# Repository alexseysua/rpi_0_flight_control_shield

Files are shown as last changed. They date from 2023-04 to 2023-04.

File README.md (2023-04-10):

# Flight Control Shield for Raspberry Pi Zero

## Description
A small hobby electronics project - hardware interface 
for intelligent autonomous UAVs. The board is designed 
to be plugged into the Raspberry Pi Zero pin socket, to 
form a consistent flight control system. It is the 
same concept as Navio2 or the Navigator, but for a smaller board. 

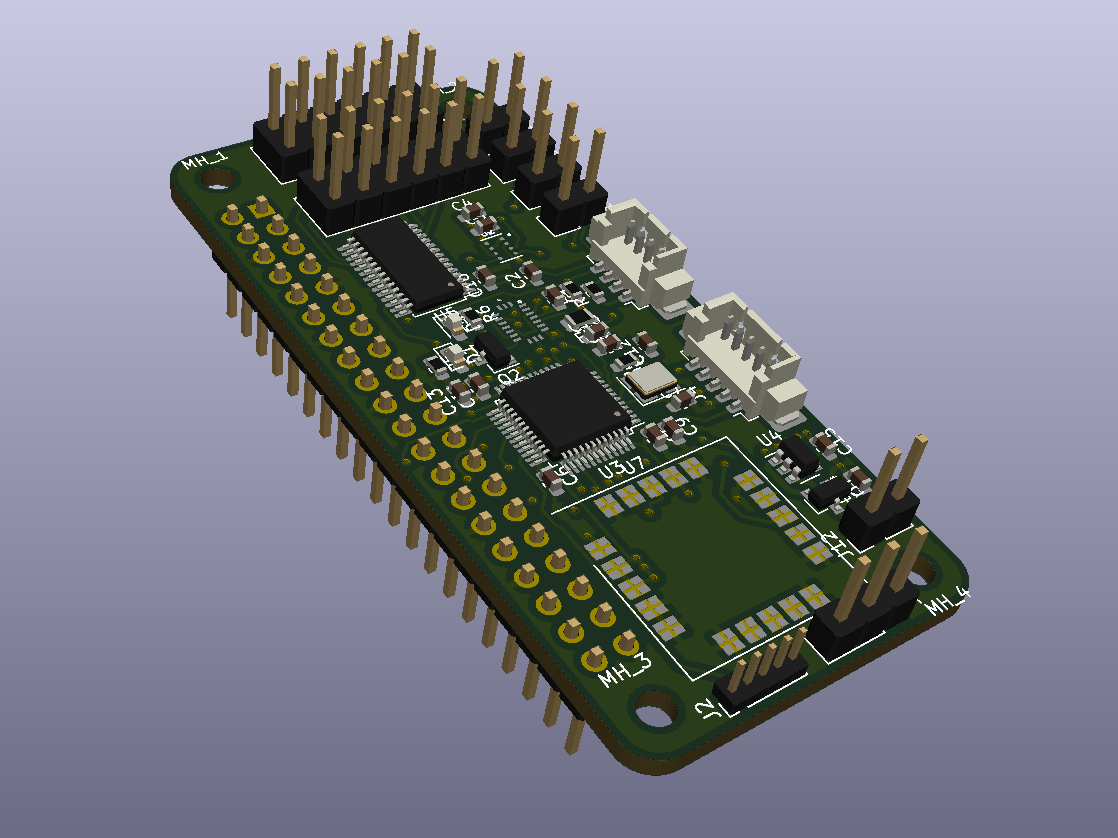
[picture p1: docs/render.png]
render


## Onboard systems
* Main CPU - STM32F103CBT 
* IMU - BMX055
* Barometer - DPS310XTSA1
* ADC sensor ports
* 12 PWM ports - PCA9685PW
* Serial and I2C extension ports
* GNSS receiver - SAM M8Q

At the moment of designing (August 2022) these were all available on JLCPCB. 

## Firmware?

Not at this time :c Slightly tweaked ArduPilot (popular stuff, it is running on ChibiOS) will probably be a good fit.

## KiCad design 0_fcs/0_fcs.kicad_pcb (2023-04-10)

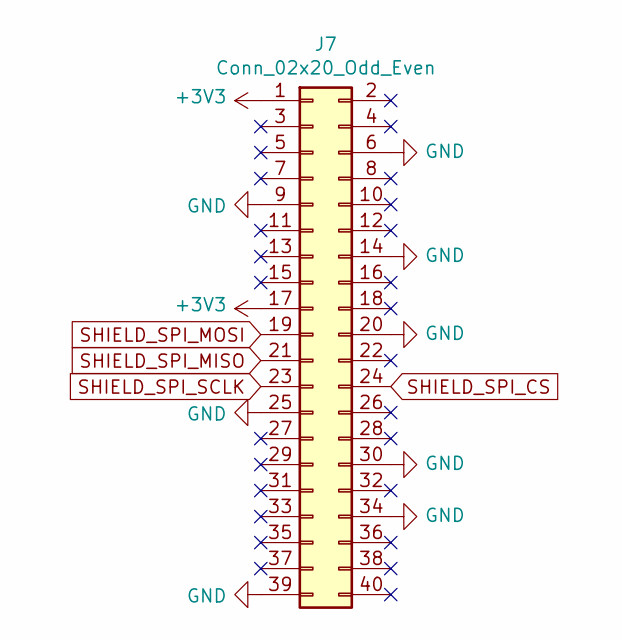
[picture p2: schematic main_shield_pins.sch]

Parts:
J7: Conn_02x20_Odd_Even; PinHeader_2x20_P2.54mm_Vertical

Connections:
GND: J7.6, J7.9, J7.14, J7.20, J7.25, J7.30, J7.34, J7.39; also elsewhere on the board
SHIELD_SPI_CS: J7.24; also elsewhere on the board
SHIELD_SPI_MISO: J7.21; also elsewhere on the board
SHIELD_SPI_MOSI: J7.19; also elsewhere on the board
SHIELD_SPI_SCLK: J7.23; also elsewhere on the board

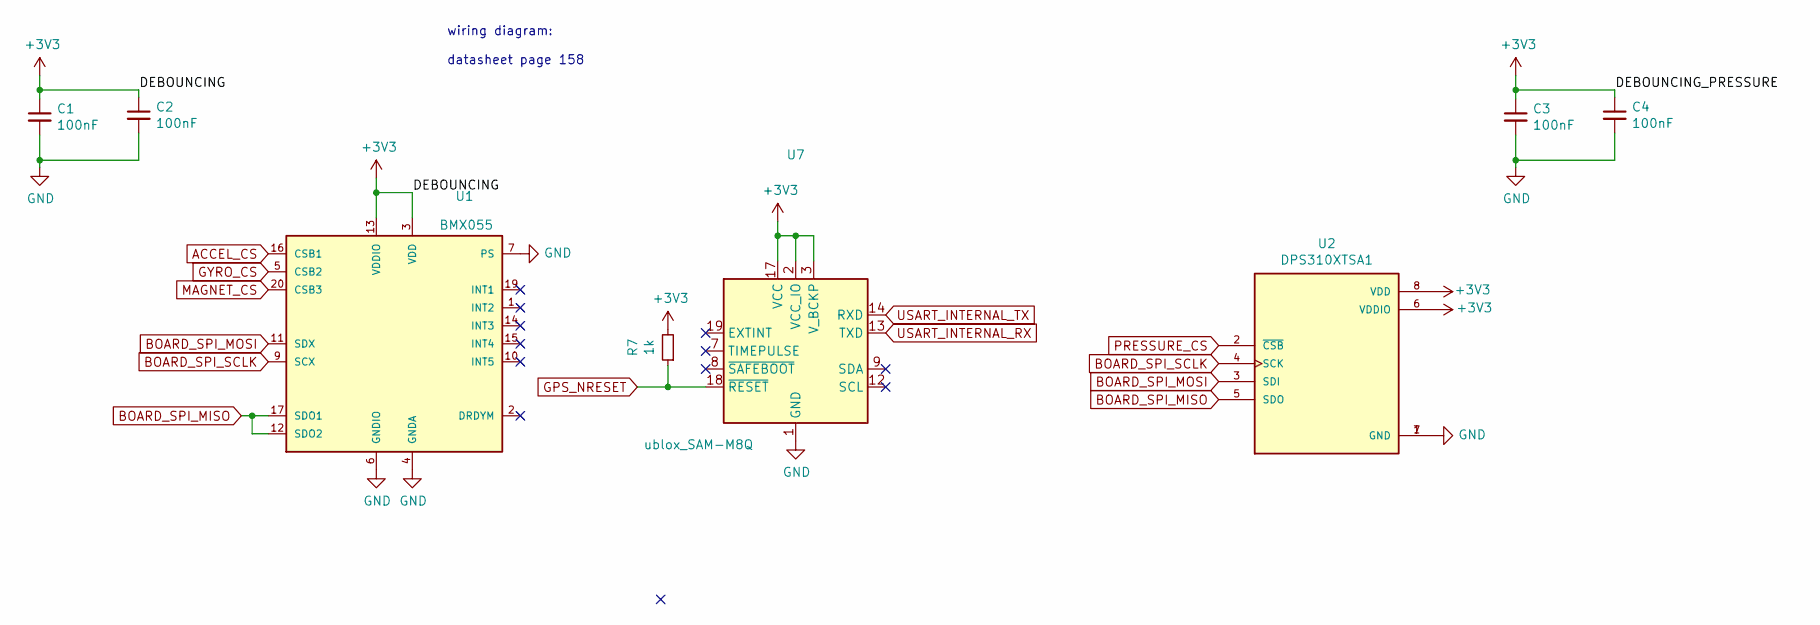
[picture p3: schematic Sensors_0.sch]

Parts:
C1, C2, C3, C4: 100nF; C_0603_1608Metric
R7: 1k; R_0603_1608Metric
U1: BMX055
U2: DPS310XTSA1; XDCR_DPS310XTSA1
U7: ublox_SAM-M8Q

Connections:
ACCEL_CS: U1.16 (CSB1); also elsewhere on the board
BOARD_SPI_MISO: U1.12 (SDO2), U1.17 (SDO1), U2.5 (SDO); also elsewhere on the board
BOARD_SPI_MOSI: U1.11 (SDX), U2.3 (SDI); also elsewhere on the board
BOARD_SPI_SCLK: U1.9 (SCX), U2.4 (SCK); also elsewhere on the board
GND: C1.2, C2.2, C3.2, C4.2, U1.4 (GNDA), U1.6 (GNDIO), U1.7 (PS), U2.1 (GND), U2.7 (GND), U7.1 (GND), U7.4 (GND), U7.5 (GND), U7.6 (GND), U7.10 (GND), U7.11 (GND), U7.15 (GND), U7.16 (GND), U7.20 (GND); also elsewhere on the board
GPS_NRESET: R7.1, U7.18 (~RESET); also elsewhere on the board
GYRO_CS: U1.5 (CSB2); also elsewhere on the board
MAGNET_CS: U1.20 (CSB3); also elsewhere on the board
PRESSURE_CS: U2.2 (~CSB); also elsewhere on the board
USART_INTERNAL_RX: U7.13 (TXD); also elsewhere on the board
USART_INTERNAL_TX: U7.14 (RXD); also elsewhere on the board

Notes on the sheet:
wiring diagram: datasheet page 158

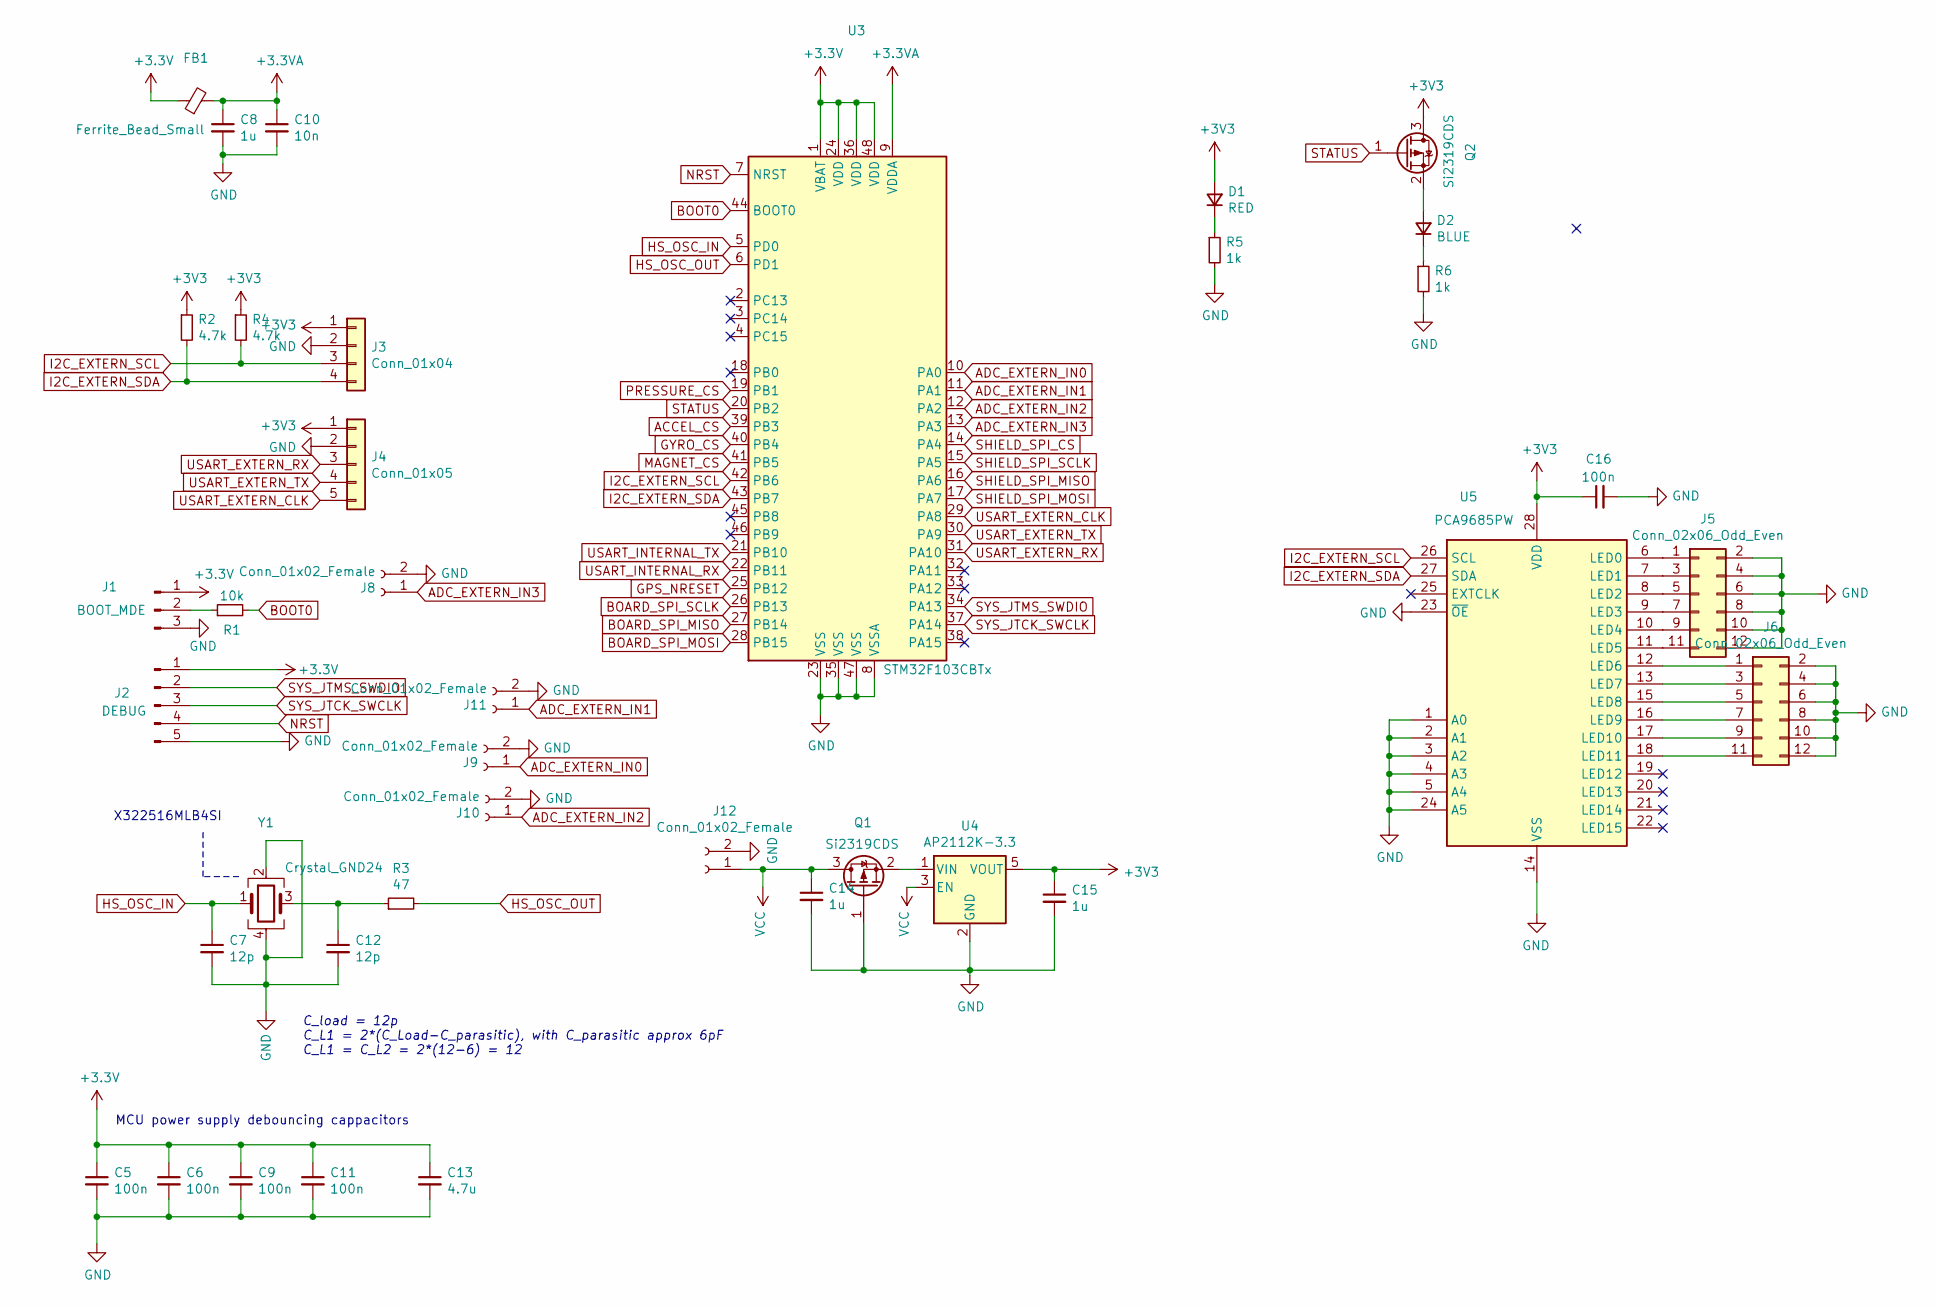
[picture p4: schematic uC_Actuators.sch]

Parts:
C5, C6, C9, C11, C16: 100n; C_0603_1608Metric
C7, C12: 12p; C_0603_1608Metric
C8, C14, C15: 1u; C_0603_1608Metric
C10: 10n; C_0603_1608Metric
C13: 4.7u; C_0603_1608Metric
D1: RED; LED_0603_1608Metric_Pad1.05x0.95mm_HandSolder
D2: BLUE; LED_0603_1608Metric_Pad1.05x0.95mm_HandSolder
FB1: Ferrite_Bead_Small; R_0805_2012Metric
J1: BOOT_MDE; PinHeader_1x03_P2.54mm_Vertical
J2: DEBUG; PinHeader_1x05_P1.27mm_Vertical
J3: Conn_01x04; Molex_PicoBlade_53398-0471_1x04-1MP_P1.25mm_Vertical
J4: Conn_01x05; Molex_PicoBlade_53398-0571_1x05-1MP_P1.25mm_Vertical
J5, J6: Conn_02x06_Odd_Even; PinHeader_2x06_P2.54mm_Vertical
J8, J9, J10, J11, J12: Conn_01x02_Female; PinHeader_1x02_P2.54mm_Vertical
Q1, Q2: Si2319CDS; SOT-23
R1: 10k; R_0603_1608Metric
R2, R4: 4.7k; R_0603_1608Metric
R3: 47; R_0603_1608Metric
R5, R6: 1k; R_0603_1608Metric
U3: STM32F103CBTx; LQFP-48_7x7mm_P0.5mm
U4: AP2112K-3.3; SOT-23-5
U5: PCA9685PW; TSSOP-28_4.4x9.7mm_P0.65mm
Y1: Crystal_GND24; Crystal_SMD_3225-4Pin_3.2x2.5mm

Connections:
+3.3VA: C8.1, C10.1, FB1.2, U3.9 (VDDA)
ACCEL_CS: U3.39 (PB3); also elsewhere on the board
ADC_EXTERN_IN0: J9.1, U3.10 (PA0)
ADC_EXTERN_IN1: J11.1, U3.11 (PA1)
ADC_EXTERN_IN2: J10.1, U3.12 (PA2)
ADC_EXTERN_IN3: J8.1, U3.13 (PA3)
BOARD_SPI_MISO: U3.27 (PB14); also elsewhere on the board
BOARD_SPI_MOSI: U3.28 (PB15); also elsewhere on the board
BOARD_SPI_SCLK: U3.26 (PB13); also elsewhere on the board
BOOT0: R1.2, U3.44 (BOOT0)
GND: C5.2, C6.2, C7.2, C8.2, C9.2, C10.2, C11.2, C12.2, C13.2, C14.2, C15.2, C16.2, J1.3, J2.5, J3.2, J4.2, J5.2, J5.4, J5.6, J5.8, J5.10, J5.12, J6.2, J6.4, J6.6, J6.8, J6.10, J6.12, J8.2, J9.2, J10.2, J11.2, J12.2, Q1.1 (G), R5.2, R6.2, U3.8 (VSSA), U3.23 (VSS), U3.35 (VSS), U3.47 (VSS), U4.2 (GND), U5.1 (A0), U5.2 (A1), U5.3 (A2), U5.4 (A3), U5.5 (A4), U5.14 (VSS), U5.23 (~OE), U5.24 (A5), Y1.2, Y1.4; also elsewhere on the board
GPS_NRESET: U3.25 (PB12); also elsewhere on the board
GYRO_CS: U3.40 (PB4); also elsewhere on the board
HS_OSC_IN: C7.1, U3.5 (PD0), Y1.1
HS_OSC_OUT: R3.2, U3.6 (PD1)
I2C_EXTERN_SCL: J3.3, R4.2, U3.42 (PB6), U5.26 (SCL)
I2C_EXTERN_SDA: J3.4, R2.2, U3.43 (PB7), U5.27 (SDA)
MAGNET_CS: U3.41 (PB5); also elsewhere on the board
NRST: J2.4, U3.7 (NRST)
unnamed: C12.1, R3.1, Y1.3
unnamed: D1.1 (K), R5.1
unnamed: D2.1 (K), R6.1
unnamed: D2.2 (A), Q2.2 (S)
unnamed: J1.2, R1.1
unnamed: J5.1, U5.6 (LED0)
unnamed: J5.3, U5.7 (LED1)
unnamed: J5.5, U5.8 (LED2)
unnamed: J5.7, U5.9 (LED3)
unnamed: J5.9, U5.10 (LED4)
unnamed: J5.11, U5.11 (LED5)
unnamed: J6.1, U5.12 (LED6)
unnamed: J6.3, U5.13 (LED7)
unnamed: J6.5, U5.15 (LED8)
unnamed: J6.7, U5.16 (LED9)
unnamed: J6.9, U5.17 (LED10)
unnamed: J6.11, U5.18 (LED11)
unnamed: Q1.2 (S), U4.1 (VIN)
PRESSURE_CS: U3.19 (PB1); also elsewhere on the board
SHIELD_SPI_CS: U3.14 (PA4); also elsewhere on the board
SHIELD_SPI_MISO: U3.16 (PA6); also elsewhere on the board
SHIELD_SPI_MOSI: U3.17 (PA7); also elsewhere on the board
SHIELD_SPI_SCLK: U3.15 (PA5); also elsewhere on the board
STATUS: Q2.1 (G), U3.20 (PB2)
SYS_JTCK_SWCLK: J2.3, U3.37 (PA14)
SYS_JTMS_SWDIO: J2.2, U3.34 (PA13)
USART_EXTERN_CLK: J4.5, U3.29 (PA8)
USART_EXTERN_RX: J4.3, U3.31 (PA10)
USART_EXTERN_TX: J4.4, U3.30 (PA9)
USART_INTERNAL_RX: U3.22 (PB11); also elsewhere on the board
USART_INTERNAL_TX: U3.21 (PB10); also elsewhere on the board
VCC: C14.1, J12.1, Q1.3 (D), U4.3 (EN)

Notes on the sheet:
C_load = 12p C_L1 = 2*(C_Load-C_parasitic), with C_parasitic approx 6pF C_L1 = C_L2 = 2*(12-6) = 12
X322516MLB4SI
MCU power supply debouncing cappacitors

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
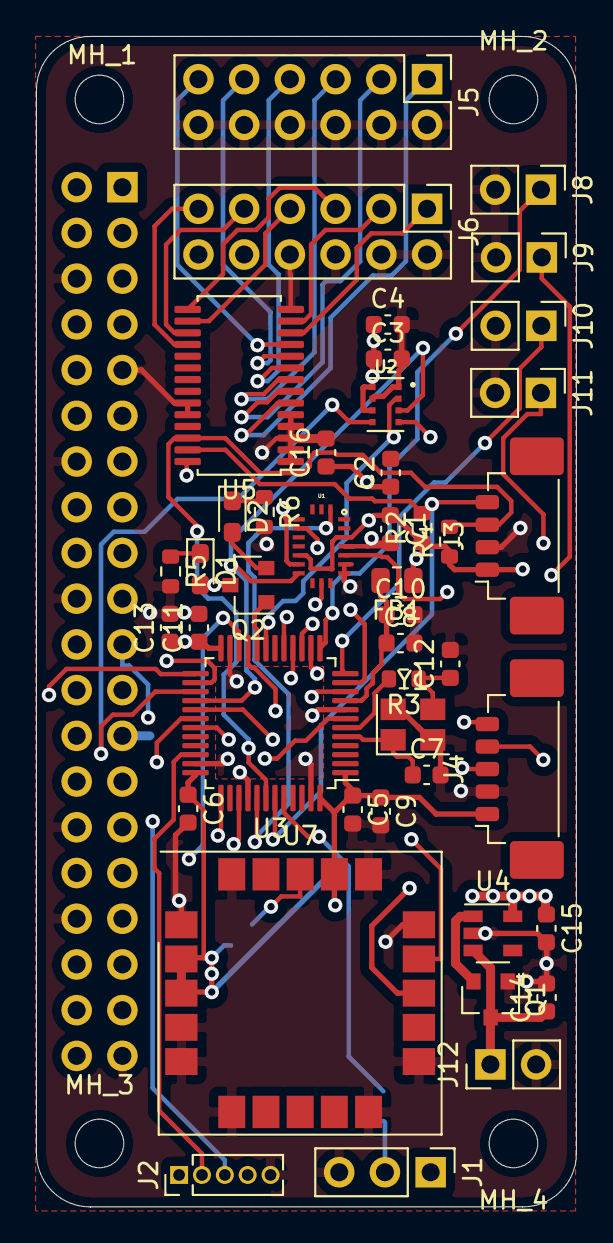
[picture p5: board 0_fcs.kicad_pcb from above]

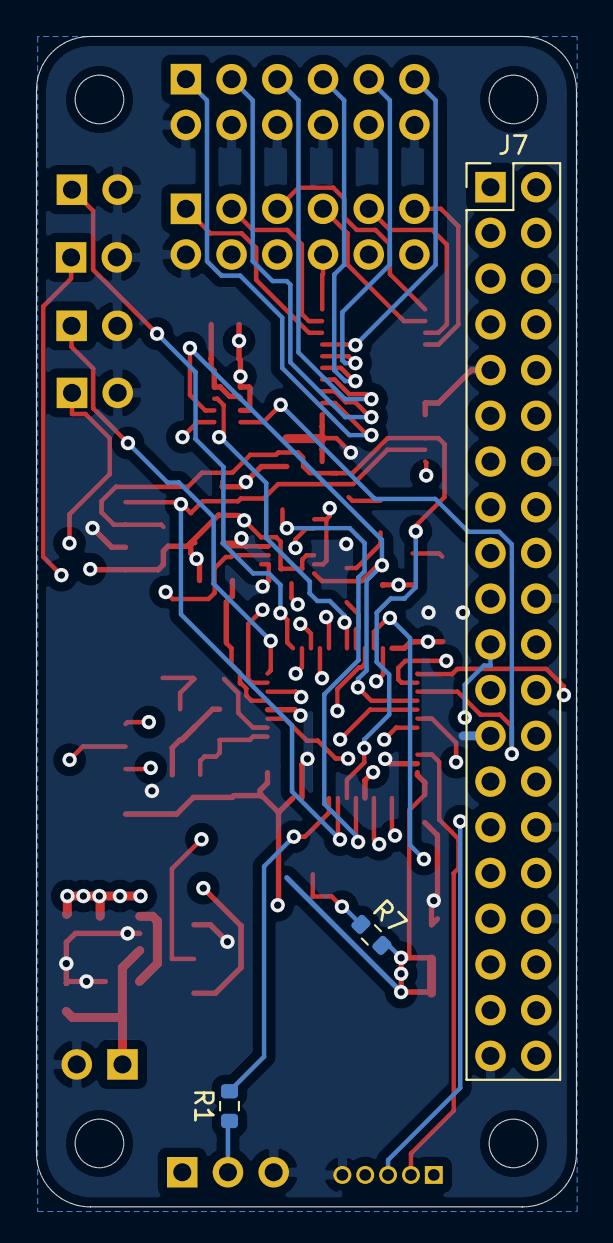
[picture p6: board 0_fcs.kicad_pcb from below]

Board: 4 copper layers, 30.0 x 65.0 mm, 51 parts (3 on the bottom side), 52 nets.

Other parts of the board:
MH_1, MH_2, MH_3, MH_4: MountingHole_2.7mm_M2.5_ISO7380

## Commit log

2022-07-24 legwork #1
    [Sensors_0.sch]
2022-07-25 Communication Legwork
    [0_fcs.sch, Sensors_0.sch, cpu.sch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]
2022-07-26 pwm legwork
    [Sensors_0.sch, main_shield_pins.sch, uC_Actuators.sch]
2023-04-10 Description!
    Project publication
    [0_fcs.kicad_pcb, 0_fcs.sch, 0_fcs_spectra.dsn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]
